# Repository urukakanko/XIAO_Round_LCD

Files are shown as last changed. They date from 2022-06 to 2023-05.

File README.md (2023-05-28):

# ラウンド液晶モジュール for XIAO RP2040（組立キット）

写真は作例です

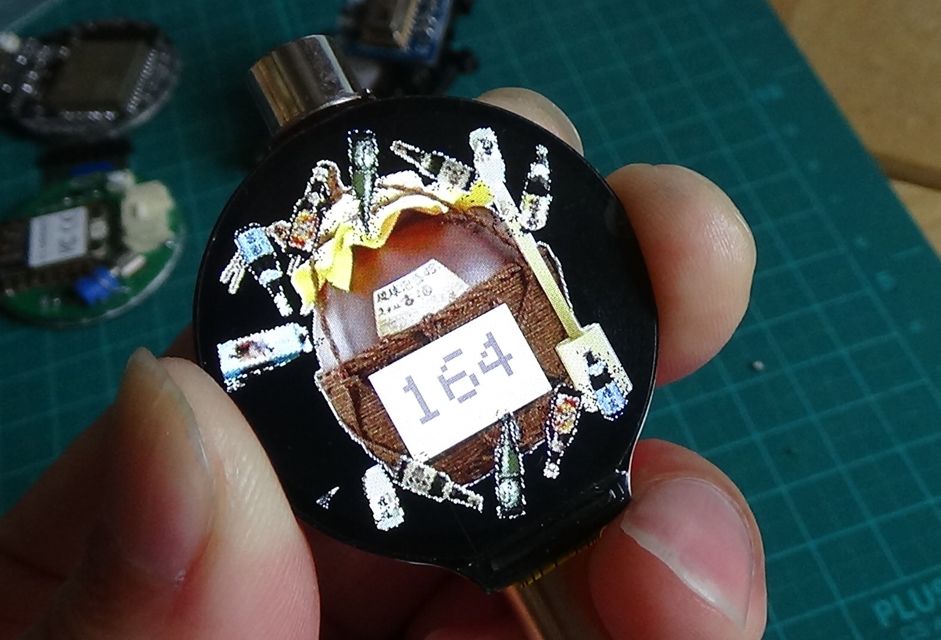
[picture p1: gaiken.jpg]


XIAO RP2040を使用して1.28インチ240ｘ240ドットの円形液晶を駆動する基板モジュールのキットです。

(XIAOシリーズでは、XIAO ESP32C3 や　nRF52840で液晶表示が出来る事を確認しています)

(なお、XIAO ESP32S3を実装する場合には懸念事項があります。以下ページで説明していますのでご参照下さい。)

https://github.com/urukakanko/XIAO_square_lcd

この製品はキットですので、ご自分で同梱の部品をハンダ付けしてください。

円形液晶の裏にXIAOを配置することで、とても小さくスリムな形状になりました。

円形液晶にはGC9A01というコントローラーが使用されていますが、対応したグラフィックライブラリが数種類公開されています。

本モジュールは「自分でSMT部品が実装できたり、グラフィックライブラリの使い方を理解して液晶モジュールを駆動出来る人」をターゲットにしております。

# 形状および回路図

以下に外形イメージを示します

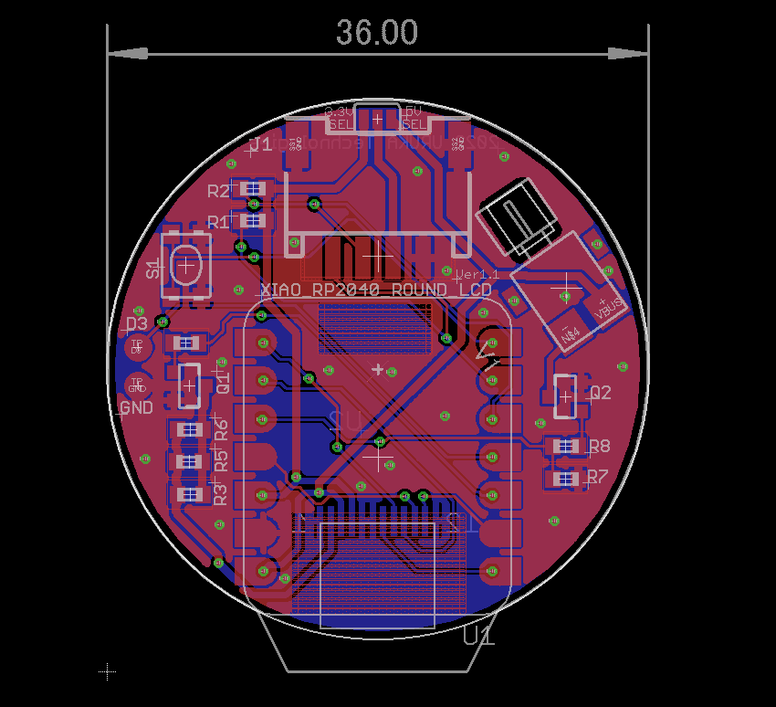
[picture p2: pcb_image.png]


以下に回路図を示します

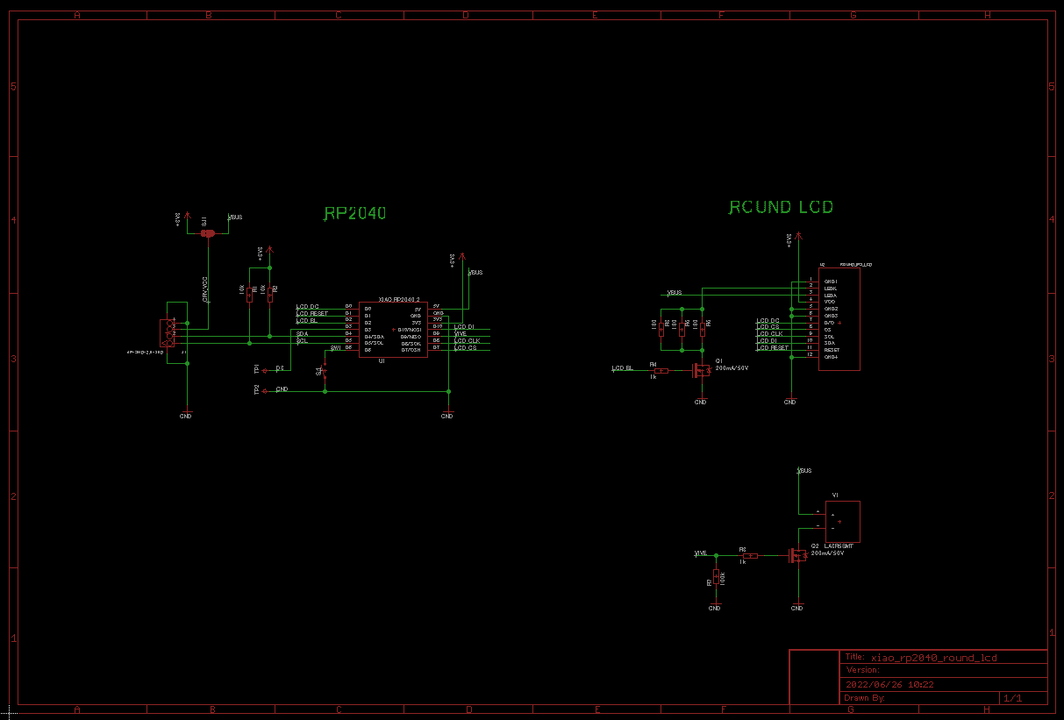
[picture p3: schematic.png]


# ピンアサイン

M5Stamp とLCDの制御信号とのピン接続は以下となります。

注意；IO番号はRP2040用です　ESP32C2では異なります

- SCLK:IO2/D8
- MOSI:IO3/D10
- DC:IO26/D0
- CS:IO1/D7
- RST:IO27/D1
- バックライト:IO28/D2　バックライトLEDのPIN設定は必ず行ってください。未設定だと端子がハイインピーダンスとなりバックライトが不安定になります。

基板上にタクトスイッチを１個実装しています

- SWポート：IO0/D6

また、I2C接続を想定したGROVEコネクタがあります

- 1PIN : SCL  IO7/D5　(I/F電圧レベルは3.3V)
- 2PIN : SDA  IO8/D4　(I/F電圧レベルは3.3V）
- 3PIN : VCC（5Vか3.3Vを選択可能）
- 4PIN : GND 

さらに小型FETを搭載すると、小型のバイブレーターなどアクチェータ１個を駆動する事が可能です

（こちらはについては扱い方次第で不具合も発生しますので、回路を読み解き自己責任で部品調達、実装してください）

- 制御ポート：IO4/D9

# 部品実装について

部品の実装（ハンダ付け方法）などについては、以下資料をご確認ください

https://github.com/urukakanko/XIAO_Round_LCD/blob/main/%E9%83%A8%E5%93%81%E5%AE%9F%E8%A3%85%E3%81%AE%E8%AA%AC%E6%98%8E.pdf

# 使用するツールやライブラリ

XIAO RP2040のArduinoやPythonの導入については以下をご確認ください

https://wiki.seeedstudio.com/XIAO-RP2040/

グラフィックライブラリについてはlovyan様のLovyanGFXにて動作確認をしています

https://github.com/lovyan03/LovyanGFX

他、GC9A01に対応したライブラリが使用可能と考えています。

なお、RP2040とGC9A01の組合せにてcircuit pythonでも動作する事を確認しています

# サンプルソース

LovyanGFXのスケッチの例より引用させて頂きました。

サンプルその１

https://github.com/urukakanko/XIAO_Round_LCD/tree/main/xiao2040_round_lcd_MeterSample

サンプルその２

https://github.com/urukakanko/XIAO_Round_LCD/tree/main/xiao2040_round_lcd_PartyParrot

サンプルその３

https://github.com/urukakanko/XIAO_Round_LCD/tree/main/xiao2040_round_clockSample

# そーたメイ様のつくるっちに対応して頂きました

ファームウェアは以下です

https://github.com/sohtamei/TuKuRutch.ext/blob/master/libraries/lovyanGFXpico/src/src.ino.uf2

ファームウェアを書込んでから、Cromeブラウザで以下にアクセスします　簡単なデモプログラムです「set config」ブロックにてROUNDXIAOを選択して下さい

https://sohta02.sakura.ne.jp/tukurutch/#000000531

# 表示例

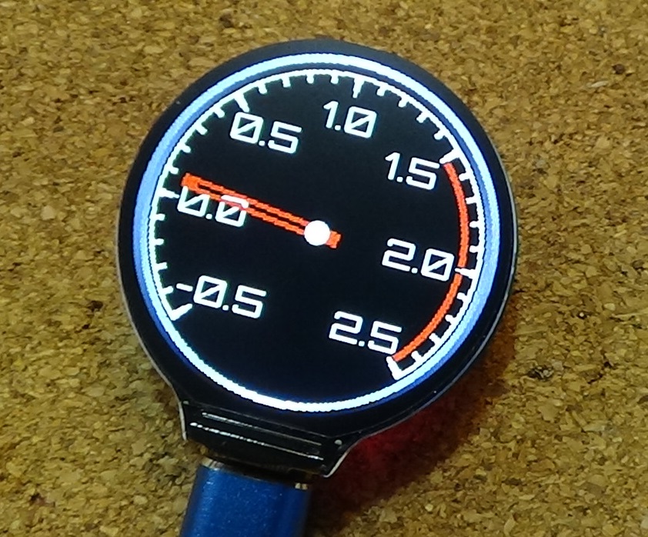
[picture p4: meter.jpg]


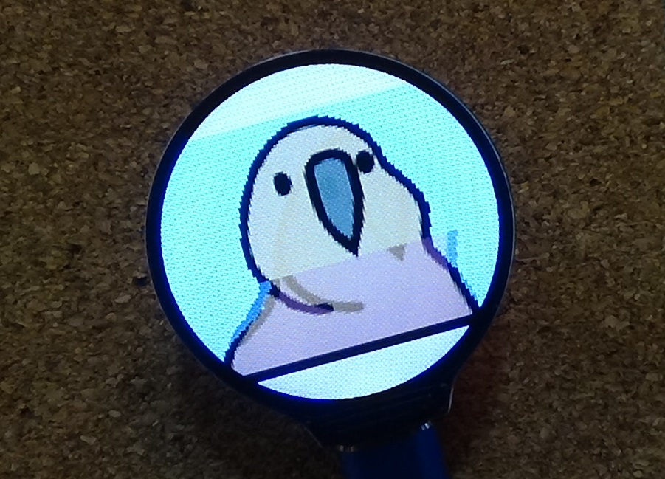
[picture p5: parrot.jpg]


# Shigezone様にて販売中です

https://www.shigezone.com/product/roundlcd1_28/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

# 製作者

ウルカテクノロジー
Hiroyuki Sunagawa

https://www.facebook.com/URUKA-Technologies-105478404379918

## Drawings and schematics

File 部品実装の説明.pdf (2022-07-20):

# 部品実装の説明

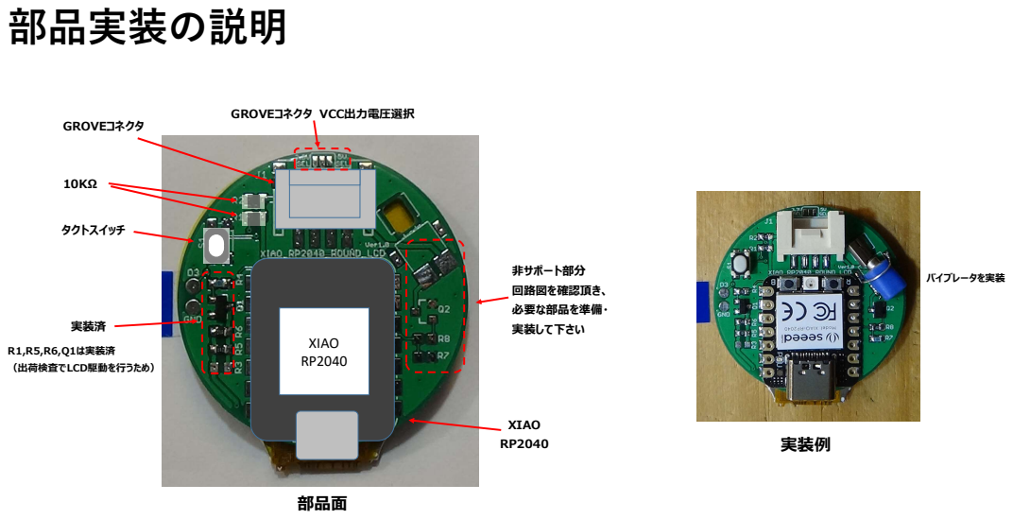
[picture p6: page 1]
タクトスイッチ; GROVEコネクタ; GROVEコネクタ VCC出力電圧選択; 非サポート部分 回路図を確認頂き、 必要な部品を準備・ 実装して下さい; 実装例; 部品面; バイブレータを実装 XIAO; XIAO RP2040; 実装済; R1,R5,R6,Q1は実装済 （出荷検査でLCD駆動を行うため）

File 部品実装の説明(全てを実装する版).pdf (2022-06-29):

# 部品実装の説明

### XIAO

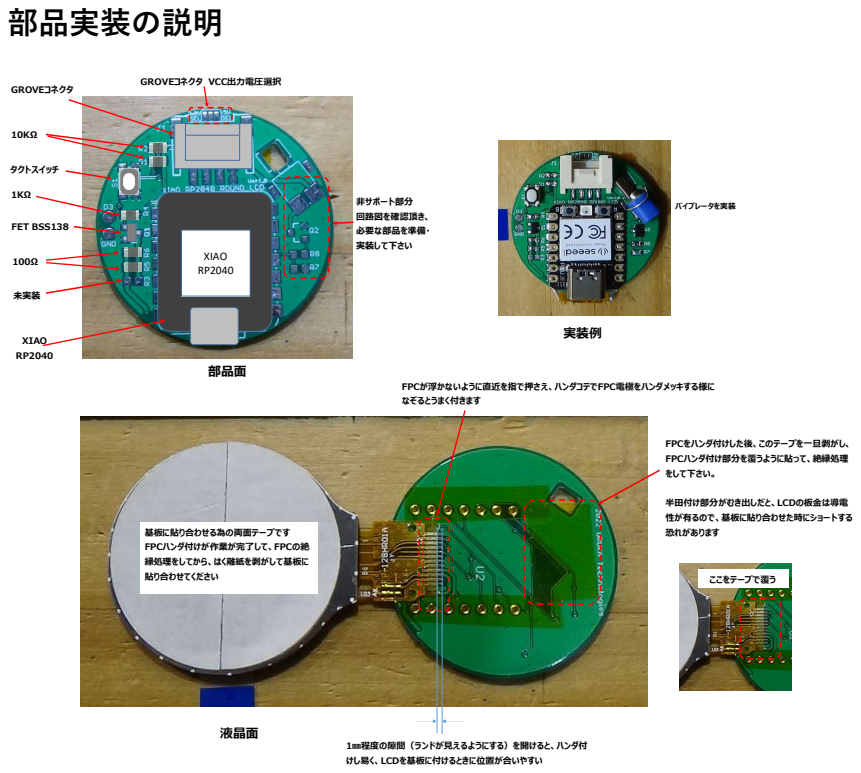
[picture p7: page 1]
タクトスイッチ; FET BSS138; 未実装; GROVEコネクタ; GROVEコネクタ VCC出力電圧選択; 非サポート部分 回路図を確認頂き、 必要な部品を準備・ 実装して下さい; 実装例; 部品面; バイブレータを実装; XIAO; 液晶面; FPCが浮かないように直近を指で押さえ、ハンダコテでFPC電極をハンダメッキする様に なぞるとうまく付きます; FPCをハンダ付けした後、このテープを一旦剥がし、 FPCハンダ付け部分を覆うように貼って、絶縁処理 をして下さい。; 半田付け部分がむき出しだと、LCDの板金は導電 性が有るので、基板に貼り合わせた時にショートする; 基板に貼り合わせる為の両面テープです; 恐れがあります; FPCハンダ付けが作業が完了して、FPCの絶 縁処理をしてから、はく離紙を剥がして基板に; 貼り合わせてください; ここをテープで覆う

1㎜程度の隙間（ランドが見えるようにする）を開けると、ハンダ付
けし易く、LCDを基板に付けるときに位置が合いやすい

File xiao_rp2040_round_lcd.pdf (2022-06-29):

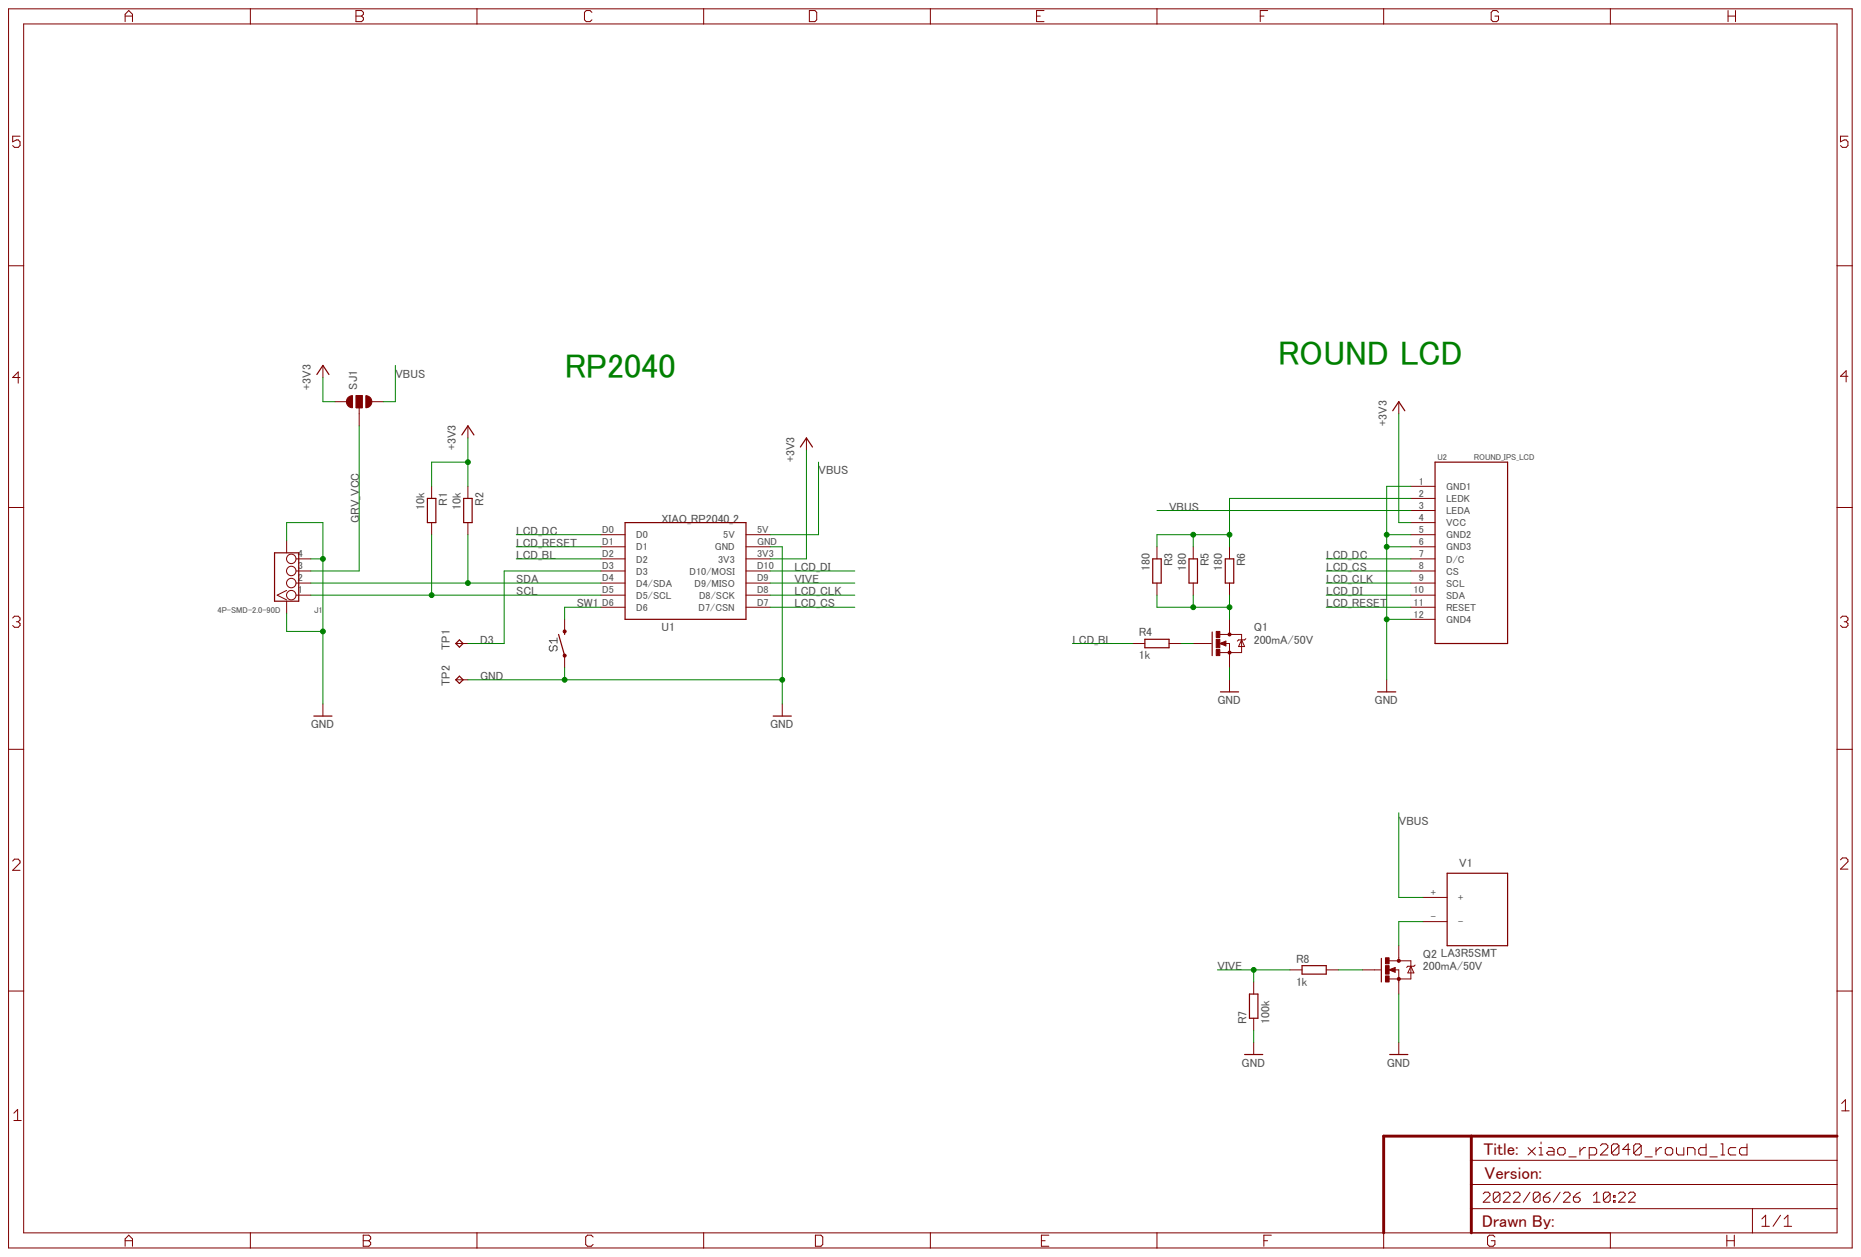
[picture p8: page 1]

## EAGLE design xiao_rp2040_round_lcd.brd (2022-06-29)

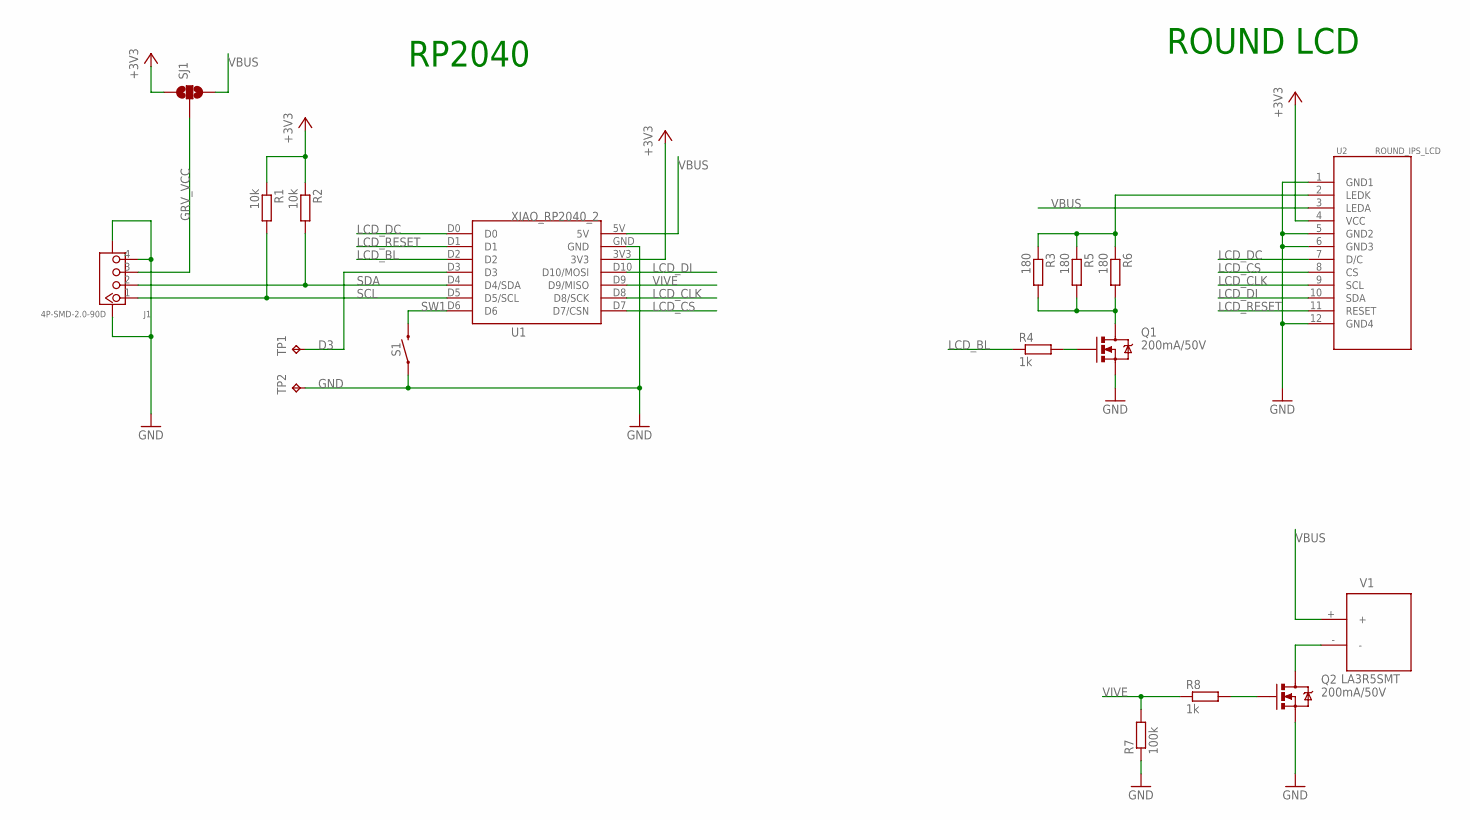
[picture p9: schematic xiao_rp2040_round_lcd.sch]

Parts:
J1: 4P-SMD-2.0-90D; HW4-SMD-2.0-90D
Q1, Q2: 200mA/50V; SOT23-3
R1, R2: 10k; R0603
R3, R5, R6: 180; R0603
R4, R8: 1k; R0603
R7: 100k; R0603
S1: TACT_SW_3X4; TACTILE_SWITCH_SMD_3X4MM
SJ1: SOLDERJUMPER_2WAYS; SJ_3
TP1, TP2: TPTP18R; TP18R
U1: XIAO_RP2040_2
U2: ROUND_IPS_LCD
V1: LA3R5SMT; LA3R5-2

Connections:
+3V3: R1.1, R2.1, SJ1.1, U1.3V3, U2.4 (VCC)
D3: TP1.TP, U1.D3
GND: J1.4, J1.SS1, J1.SS2, Q1.2 (S), Q2.2 (S), R7.1, S1.1, S1.2 (1), TP2.TP, U1.GND, U2.1 (GND1), U2.5 (GND2), U2.6 (GND3), U2.12 (GND4)
GRV_VCC: J1.3, SJ1.2
LCD_BL: R4.1, U1.D2
LCD_CLK: U1.D8 (D8/SCK), U2.9 (SCL)
LCD_CS: U1.D7 (D7/CSN), U2.8 (CS)
LCD_DC: U1.D0, U2.7 (D/C)
LCD_DI: U1.D10 (D10/MOSI), U2.10 (SDA)
LCD_RESET: U1.D1, U2.11 (RESET)
LED_K: R3.1, R5.1, R6.1, U2.2 (LEDK)
unnamed: Q1.1 (G), R4.2
unnamed: Q1.3 (D), R3.2, R5.2, R6.2
unnamed: Q2.3 (D), V1.-
unnamed: Q2.1 (G), R8.2
SCL: J1.1, R1.2, U1.D5 (D5/SCL)
SDA: J1.2, R2.2, U1.D4 (D4/SDA)
SW1: S1.3 (2), S1.4 (2), U1.D6
VBUS: SJ1.3, U1.5V, U2.3 (LEDA), V1.+
VIVE: R7.2, R8.1, U1.D9 (D9/MISO)

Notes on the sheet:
RP2040
ROUND LCD

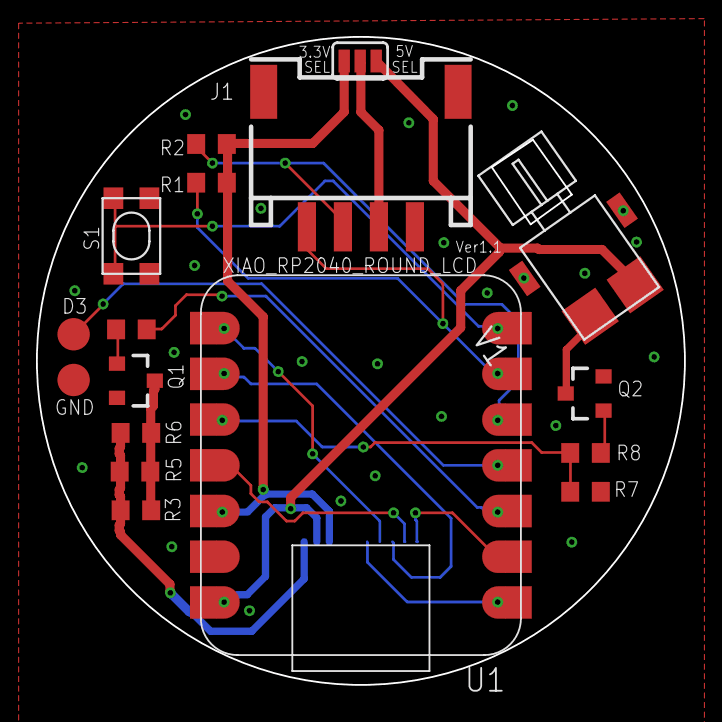
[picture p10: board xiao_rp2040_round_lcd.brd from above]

Board: 2 copper layers, 36.0 x 36.0 mm, 18 parts (1 on the bottom side), 20 nets.

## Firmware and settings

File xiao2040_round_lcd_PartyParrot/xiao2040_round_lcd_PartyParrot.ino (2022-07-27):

#define LGFX_USE_V1
#include <LovyanGFX.hpp>


class LGFX_RPICO_SPI_GC9A01 : public lgfx::LGFX_Device
{
    lgfx::Panel_GC9A01      _panel_instance;
    lgfx::Bus_SPI       _bus_instance;   // SPIバスのインスタンス
    //lgfx::Light_PWM     _light_instance;
  public:
    LGFX_RPICO_SPI_GC9A01(void)
    {
      { // バス制御の設定を行います。
        auto cfg = _bus_instance.config();    // バス設定用の構造体を取得します。

        // SPIバスの設定
        cfg.spi_host = 0 ;//SPI2_HOST;     // 使用するSPIを選択  ESP32-S2,C3 : SPI2_HOST or SPI3_HOST / ESP32 : VSPI_HOST or HSPI_HOST
        // ※ ESP-IDFバージョンアップに伴い、VSPI_HOST , HSPI_HOSTの記述は非推奨になるため、エラーが出る場合は代わりにSPI2_HOST , SPI3_HOSTを使用してください。
        cfg.spi_mode = 0;             // SPI通信モードを設定 (0 ~ 3)
        cfg.freq_write = 40000000;    // 送信時のSPIクロック (最大80MHz, 80MHzを整数で割った値に丸められます)
        cfg.freq_read  = 16000000;    // 受信時のSPIクロック
        //     cfg.spi_3wire  = true;        // 受信をMOSIピンで行う場合はtrueを設定
        //      cfg.use_lock   = true;        // トランザクションロックを使用する場合はtrueを設定
        //      cfg.dma_channel = SPI_DMA_CH_AUTO; // 使用するDMAチャンネルを設定 (0=DMA不使用 / 1=1ch / 2=ch / SPI_DMA_CH_AUTO=自動設定)
        // ※ ESP-IDFバージョンアップに伴い、DMAチャンネルはSPI_DMA_CH_AUTO(自動設定)が推奨になりました。1ch,2chの指定は非推奨になります。
        cfg.pin_sclk  = D8;  //IO2            // SPIのSCLKピン番号を設定
        cfg.pin_mosi  = D10; //IO3            // SPIのMOSIピン番号を設定
        cfg.pin_miso  = -1;            // SPIのMISOピン番号を設定 (-1 = disable)
        cfg.pin_dc    = D0;  //IO26           // SPIのD/Cピン番号を設定  (-1 = disable)
        // SDカードと共通のSPIバスを使う場合、MISOは省略せず必ず設定してください。
        _bus_instance.config(cfg);    // 設定値をバスに反映します。
        _panel_instance.setBus(&_bus_instance);      // バスをパネルにセットします。
      }

      { // 表示パネル制御の設定を行います。
        auto cfg = _panel_instance.config();    // 表示パネル設定用の構造体を取得します。
        cfg.pin_cs           =    D7;//IO1  // CSが接続されているピン番号   (-1 = disable)
        cfg.pin_rst          =    D1;//IO27  // RSTが接続されているピン番号  (-1 = disable)
        cfg.pin_busy         =    -1;  // BUSYが接続されているピン番号 (-1 = disable)
        // ※ 以下の設定値はパネル毎に一般的な初期値が設定されていますので、不明な項目はコメントアウトして試してみてください。
        cfg.memory_width     =   240;  // ドライバICがサポートしている最大の幅
        cfg.memory_height    =   240;  // ドライバICがサポートしている最大の高さ
        cfg.panel_width      =   240;  // 実際に表示可能な幅
        cfg.panel_height     =   240;  // 実際に表示可能な高さ
        cfg.offset_x         =     0;  // パネルのX方向オフセット量
        cfg.offset_y         =     0;  // パネルのY方向オフセット量
        cfg.offset_rotation  =     0;  // 回転方向の値のオフセット 0~7 (4~7は上下反転)
        cfg.dummy_read_pixel =     8;  // ピクセル読出し前のダミーリードのビット数
        cfg.dummy_read_bits  =     1;  // ピクセル以外のデータ読出し前のダミーリードのビット数
        cfg.readable         =  true;  // データ読出しが可能な場合 trueに設定
        cfg.invert           =  true;  // パネルの明暗が反転してしまう場合 trueに設定
        cfg.rgb_order        = false;  // パネルの赤と青が入れ替わってしまう場合 trueに設定
        cfg.dlen_16bit       = false;  // データ長を16bit単位で送信するパネルの場合 trueに設定
        cfg.bus_shared       =  true;  // SDカードとバスを共有している場合 trueに設定(drawJpgFile等でバス制御を行います)

        _panel_instance.config(cfg);
      }
      /*
        { // バックライト制御の設定を行います。（必要なければ削除）
          auto cfg = _light_instance.config();    // バックライト設定用の構造体を取得します。

          cfg.pin_bl = 7;              // バックライトが接続されているピン番号
          cfg.invert = false;           // バックライトの輝度を反転させる場合 true
          cfg.freq   = 44100;           // バックライトのPWM周波数
          cfg.pwm_channel = 3;          // 使用するPWMのチャンネル番号

          _light_instance.config(cfg);
          _panel_instance.setLight(&_light_instance);  // バックライトをパネルにセットします。
        }
      */
      setPanel(&_panel_instance); // 使用するパネルをセットします。
    }

};

LGFX_RPICO_SPI_GC9A01 lcd;

static LGFX_Sprite sprite[10];

static std::uint32_t count = 0;
static float zoom = 0;

extern const unsigned char parrot00[];
extern const unsigned char parrot01[];
extern const unsigned char parrot02[];
extern const unsigned char parrot03[];
extern const unsigned char parrot04[];
extern const unsigned char parrot05[];
extern const unsigned char parrot06[];
extern const unsigned char parrot07[];
extern const unsigned char parrot08[];
extern const unsigned char parrot09[];

#define bl D2 //IO28  バックライトピン設定
#define vib D9 //IO4   バイブレータピン設定

void setup()
{
  pinMode(bl, OUTPUT);
  digitalWrite(bl, HIGH);
  pinMode(vib, OUTPUT);
  digitalWrite(vib, LOW);
  
  lcd.init();
  lcd.setRotation(0);
  if (lcd.width() < lcd.height()) { lcd.setRotation(lcd.getRotation() ^ 1); }

  zoom = (float)lcd.width() / 128;
  float ztmp = (float)lcd.height() / 96;
  if (zoom > ztmp) { zoom = ztmp; }

  lcd.setPivot(lcd.width() >> 1, lcd.height() >> 1);
  lcd.fillScreen(0xFFFFFFU);

  sprite[0].createFromBmp(parrot00);
  sprite[1].createFromBmp(parrot01);
  sprite[2].createFromBmp(parrot02);
  sprite[3].createFromBmp(parrot03);
  sprite[4].createFromBmp(parrot04);
  sprite[5].createFromBmp(parrot05);
  sprite[6].createFromBmp(parrot06);
  sprite[7].createFromBmp(parrot07);
  sprite[8].createFromBmp(parrot08);
  sprite[9].createFromBmp(parrot09);
}

void loop() {
  if (++count == 10) count = 0;
  sprite[count].pushRotateZoom(&lcd, lcd.width() >> 1, lcd.height() >> 1, 0, zoom, zoom);
}

// The parrot image data is from this site.
// https://cultofthepartyparrot.com/

constexpr unsigned char parrot00[] = {
0x42, 0x4D, 0xEC, 0x0D, 0x00, 0x00, 0x00, 0x00, 0x00, 0x00, 0x32, 0x04, 0x00, 0x00, 0x28, 0x00, 
0x00, 0x00, 0x80, 0x00, 0x00, 0x00, 0x60, 0x00, 0x00, 0x00, 0x01, 0x00, 0x08, 0x00, 0x01, 0x00, 
0x00, 0x00, 0xBA, 0x09, 0x00, 0x00, 0x13, 0x0B, 0x00, 0x00, 0x13, 0x0B, 0x00, 0x00, 0xFF, 0x00, 
0x00, 0x00, 0xFF, 0x00, 0x00, 0x00, 0x00, 0x01, 0x00, 0x00, 0x00, 0x01, 0x08, 0x00, 0x08, 0x04, 
0x00, 0x00, 0x02, 0x06, 0x03, 0x00, 0x0B, 0x05, 0x08, 0x00, 0x06, 0x0A, 0x07, 0x00, 0x06, 0x08, 
0x0E, 0x00, 0x0E, 0x0B, 0x04, 0x00, 0x0F, 0x07, 0x12, 0x00, 0x0B, 0x0C, 0x12, 0x00, 0x16, 0x0B, 
0x12, 0x00, 0x0C, 0x0B, 0x17, 0x00, 0x0C, 0x10, 0x0D, 0x00, 0x13, 0x11, 0x08, 0x00, 0x12, 0x0C, 
0x1C, 0x00, 0x19, 0x0C, 0x1B, 0x00, 0x18, 0x10, 0x10, 0x00, 0x0A, 0x0D, 0x21, 0x00, 0x08, 0x13, 
0x10, 0x00, 0x1E, 0x0E, 0x1A, 0x00, 0x0A, 0x12, 0x18, 0x00, 0x1B, 0x15, 0x0E, 0x00, 0x1C, 0x10, 
0x1F, 0x00, 0x14, 0x11, 0x1F, 0x00, 0x12, 0x15, 0x13, 0x00, 0x23, 0x10, 0x24, 0x00, 0x1B, 0x10, 
0x28, 0x00, 0x0E, 0x15, 0x1C, 0x00, 0x0E, 0x1A, 0x0D, 0x00, 0x19, 0x19, 0x0D, 0x00, 0x11, 0x13, 
0x25, 0x00, 0x23, 0x13, 0x1F, 0x00, 0x12, 0x1A, 0x15, 0x00, 0x12, 0x13, 0x2E, 0x00, 0x25, 0x1A, 
0x16, 0x00, 0x2E, 0x14, 0x30, 0x00, 0x17, 0x18, 0x2C, 0x00, 0x20, 0x20, 0x0F, 0x00, 0x2D, 0x19, 
0x23, 0x00, 0x13, 0x1C, 0x23, 0x00, 0x13, 0x21, 0x13, 0x00, 0x17, 0x1F, 0x1A, 0x00, 0x24, 0x16, 
0x34, 0x00, 0x32, 0x14, 0x37, 0x00, 0x17, 0x17, 0x38, 0x00, 0x2E, 0x19, 0x2B, 0x00, 0x1C, 0x1D, 
0x32, 0x00, 0x15, 0x21, 0x29, 0x00, 0x32, 0x23, 0x1B, 0x00, 0x26, 0x26, 0x15, 0x00, 0x1D, 0x25, 
0x20, 0x00, 0x16, 0x29, 0x15, 0x00, 0x3B, 0x1A, 0x3B, 0x00, 0x1D, 0x1B, 0x43, 0x00, 0x2F, 0x1B, 
0x40, 0x00, 0x36, 0x1E, 0x34, 0x00, 0x3D, 0x20, 0x33, 0x00, 0x23, 0x21, 0x3D, 0x00, 0x3B, 0x20, 
0x3D, 0x00, 0x3A, 0x29, 0x22, 0x00, 0x44, 0x1D, 0x47, 0x00, 0x1F, 0x1F, 0x4D, 0x00, 0x2C, 0x2D, 
0x1A, 0x00, 0x1A, 0x28, 0x31, 0x00, 0x22, 0x2B, 0x27, 0x00, 0x37, 0x1F, 0x4D, 0x00, 0x3F, 0x23, 
0x41, 0x00, 0x26, 0x27, 0x48, 0x00, 0x47, 0x27, 0x3E, 0x00, 0x4E, 0x22, 0x4E, 0x00, 0x1F, 0x2F, 
0x39, 0x00, 0x25, 0x32, 0x2D, 0x00, 0x25, 0x26, 0x56, 0x00, 0x3F, 0x24, 0x59, 0x00, 0x1F, 0x39, 
0x1E, 0x00, 0x35, 0x37, 0x1E, 0x00, 0x47, 0x33, 0x27, 0x00, 0x53, 0x24, 0x58, 0x00, 0x4F, 0x2B, 
0x42, 0x00, 0x2B, 0x2C, 0x50, 0x00, 0x28, 0x28, 0x5F, 0x00, 0x4D, 0x2A, 0x4D, 0x00, 0x2A, 0x38, 
0x30, 0x00, 0x55, 0x30, 0x49, 0x00, 0x30, 0x2F, 0x59, 0x00, 0x60, 0x29, 0x62, 0x00, 0x2B, 0x2C, 
0x6B, 0x00, 0x49, 0x2B, 0x68, 0x00, 0x55, 0x2F, 0x59, 0x00, 0x26, 0x3A, 0x45, 0x00, 0x31, 0x3F, 
0x36, 0x00, 0x58, 0x3E, 0x2E, 0x00, 0x65, 0x2B, 0x6B, 0x00, 0x26, 0x46, 0x26, 0x00, 0x2F, 0x30, 
0x6F, 0x00, 0x5C, 0x32, 0x59, 0x00, 0x47, 0x46, 0x24, 0x00, 0x62, 0x36, 0x52, 0x00, 0x37, 0x36, 
0x61, 0x00, 0x51, 0x31, 0x75, 0x00, 0x32, 0x33, 0x7A, 0x00, 0x2A, 0x41, 0x4E, 0x00, 0x5E, 0x44, 
0x34, 0x00, 0x38, 0x47, 0x3D, 0x00, 0x65, 0x38, 0x66, 0x00, 0x75, 0x32, 0x79, 0x00, 0x2D, 0x52, 
0x2D, 0x00, 0x58, 0x35, 0x81, 0x00, 0x37, 0x37, 0x86, 0x00, 0x69, 0x4A, 0x37, 0x00, 0x3C, 0x3E, 
0x71, 0x00, 0x72, 0x3E, 0x61, 0x00, 0x53, 0x52, 0x2C, 0x00, 0x39, 0x4D, 0x46, 0x00, 0x30, 0x49, 
0x57, 0x00, 0x62, 0x37, 0x86, 0x00, 0x32, 0x58, 0x2B, 0x00, 0x72, 0x3D, 0x71, 0x00, 0x58, 0x56, 
0x30, 0x00, 0x2F, 0x5B, 0x31, 0x00, 0x3E, 0x3D, 0x93, 0x00, 0x86, 0x3A, 0x88, 0x00, 0x73, 0x52, 
0x3E, 0x00, 0x3F, 0x54, 0x4B, 0x00, 0x45, 0x45, 0x7E, 0x00, 0x69, 0x3D, 0x90, 0x00, 0x85, 0x48, 
0x6F, 0x00, 0x81, 0x45, 0x81, 0x00, 0x41, 0x43, 0xA1, 0x00, 0x37, 0x56, 0x66, 0x00, 0x7F, 0x5A, 
0x41, 0x00, 0x46, 0x5C, 0x4F, 0x00, 0x93, 0x3F, 0x98, 0x00, 0x38, 0x66, 0x36, 0x00, 0x63, 0x63, 
0x34, 0x00, 0x73, 0x43, 0xA0, 0x00, 0x4F, 0x4D, 0x8E, 0x00, 0x9C, 0x42, 0xA1, 0x00, 0x3D, 0x5D, 
0x6D, 0x00, 0x4C, 0x63, 0x55, 0x00, 0x95, 0x51, 0x7C, 0x00, 0x89, 0x62, 0x4A, 0x00, 0x9F, 0x45, 
0xA5, 0x00, 0x4B, 0x4B, 0xB3, 0x00, 0x50, 0x53, 0x97, 0x00, 0x51, 0x68, 0x5A, 0x00, 0x7E, 0x4A, 
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
};

constexpr unsigned char parrot01[] = {
0x42, 0x4D, 0xFE, 0x0D, 0x00, 0x00, 0x00, 0x00, 0x00, 0x00, 0x32, 0x04, 0x00, 0x00, 0x28, 0x00, 
0x00, 0x00, 0x80, 0x00, 0x00, 0x00, 0x60, 0x00, 0x00, 0x00, 0x01, 0x00, 0x08, 0x00, 0x01, 0x00, 
0x00, 0x00, 0xCC, 0x09, 0x00, 0x00, 0x13, 0x0B, 0x00, 0x00, 0x13, 0x0B, 0x00, 0x00, 0xFF, 0x00, 
0x00, 0x00, 0xFF, 0x00, 0x00, 0x00, 0x00, 0x01, 0x00, 0x00, 0x00, 0x01, 0x08, 0x00, 0x08, 0x04, 
0x00, 0x00, 0x02, 0x06, 0x03, 0x00, 0x0B, 0x05, 0x08, 0x00, 0x06, 0x0A, 0x07, 0x00, 0x06, 0x08, 
0x0E, 0x00, 0x0E, 0x0B, 0x04, 0x00, 0x0F, 0x07, 0x12, 0x00, 0x0B, 0x0C, 0x12, 0x00, 0x16, 0x0B, 
0x12, 0x00, 0x0C, 0x0B, 0x17, 0x00, 0x0C, 0x10, 0x0D, 0x00, 0x13, 0x11, 0x08, 0x00, 0x12, 0x0C, 
0x1C, 0x00, 0x19, 0x0C, 0x1B, 0x00, 0x18, 0x10, 0x10, 0x00, 0x0A, 0x0D, 0x21, 0x00, 0x08, 0x13, 
0x10, 0x00, 0x1E, 0x0E, 0x1A, 0x00, 0x0A, 0x12, 0x18, 0x00, 0x1B, 0x15, 0x0E, 0x00, 0x1C, 0x10, 
0x1F, 0x00, 0x14, 0x11, 0x1F, 0x00, 0x12, 0x15, 0x13, 0x00, 0x23, 0x10, 0x24, 0x00, 0x1B, 0x10, 
0x28, 0x00, 0x0E, 0x15, 0x1C, 0x00, 0x0E, 0x1A, 0x0D, 0x00, 0x19, 0x19, 0x0D, 0x00, 0x11, 0x13, 
0x25, 0x00, 0x23, 0x13, 0x1F, 0x00, 0x12, 0x1A, 0x15, 0x00, 0x12, 0x13, 0x2E, 0x00, 0x25, 0x1A, 
0x16, 0x00, 0x2E, 0x14, 0x30, 0x00, 0x17, 0x18, 0x2C, 0x00, 0x20, 0x20, 0x0F, 0x00, 0x2D, 0x19, 
0x23, 0x00, 0x13, 0x1C, 0x23, 0x00, 0x13, 0x21, 0x13, 0x00, 0x17, 0x1F, 0x1A, 0x00, 0x24, 0x16, 
0x34, 0x00, 0x32, 0x14, 0x37, 0x00, 0x17, 0x17, 0x38, 0x00, 0x2E, 0x19, 0x2B, 0x00, 0x1C, 0x1D, 
0x32, 0x00, 0x15, 0x21, 0x29, 0x00, 0x32, 0x23, 0x1B, 0x00, 0x26, 0x26, 0x15, 0x00, 0x1D, 0x25, 
0x20, 0x00, 0x16, 0x29, 0x15, 0x00, 0x3B, 0x1A, 0x3B, 0x00, 0x1D, 0x1B, 0x43, 0x00, 0x2F, 0x1B, 
0x40, 0x00, 0x36, 0x1E, 0x34, 0x00, 0x3D, 0x20, 0x33, 0x00, 0x23, 0x21, 0x3D, 0x00, 0x3B, 0x20, 
0x3D, 0x00, 0x3A, 0x29, 0x22, 0x00, 0x44, 0x1D, 0x47, 0x00, 0x1F, 0x1F, 0x4D, 0x00, 0x2C, 0x2D, 
0x1A, 0x00, 0x1A, 0x28, 0x31, 0x00, 0x22, 0x2B, 0x27, 0x00, 0x37, 0x1F, 0x4D, 0x00, 0x3F, 0x23, 
0x41, 0x00, 0x26, 0x27, 0x48, 0x00, 0x47, 0x27, 0x3E, 0x00, 0x4E, 0x22, 0x4E, 0x00, 0x1F, 0x2F, 
0x39, 0x00, 0x25, 0x32, 0x2D, 0x00, 0x25, 0x26, 0x56, 0x00, 0x3F, 0x24, 0x59, 0x00, 0x1F, 0x39, 
0x1E, 0x00, 0x35, 0x37, 0x1E, 0x00, 0x47, 0x33, 0x27, 0x00, 0x53, 0x24, 0x58, 0x00, 0x4F, 0x2B, 
0x42, 0x00, 0x2B, 0x2C, 0x50, 0x00, 0x28, 0x28, 0x5F, 0x00, 0x4D, 0x2A, 0x4D, 0x00, 0x2A, 0x38, 
0x30, 0x00, 0x55, 0x30, 0x49, 0x00, 0x30, 0x2F, 0x59, 0x00, 0x60, 0x29, 0x62, 0x00, 0x2B, 0x2C, 
0x6B, 0x00, 0x49, 0x2B, 0x68, 0x00, 0x55, 0x2F, 0x59, 0x00, 0x26, 0x3A, 0x45, 0x00, 0x31, 0x3F, 
0x36, 0x00, 0x58, 0x3E, 0x2E, 0x00, 0x65, 0x2B, 0x6B, 0x00, 0x26, 0x46, 0x26, 0x00, 0x2F, 0x30, 
0x6F, 0x00, 0x5C, 0x32, 0x59, 0x00, 0x47, 0x46, 0x24, 0x00, 0x62, 0x36, 0x52, 0x00, 0x37, 0x36, 
0x61, 0x00, 0x51, 0x31, 0x75, 0x00, 0x32, 0x33, 0x7A, 0x00, 0x2A, 0x41, 0x4E, 0x00, 0x5E, 0x44, 
0x34, 0x00, 0x38, 0x47, 0x3D, 0x00, 0x65, 0x38, 0x66, 0x00, 0x75, 0x32, 0x79, 0x00, 0x2D, 0x52, 
0x2D, 0x00, 0x58, 0x35, 0x81, 0x00, 0x37, 0x37, 0x86, 0x00, 0x69, 0x4A, 0x37, 0x00, 0x3C, 0x3E, 
0x71, 0x00, 0x72, 0x3E, 0x61, 0x00, 0x53, 0x52, 0x2C, 0x00, 0x39, 0x4D, 0x46, 0x00, 0x30, 0x49, 
0x57, 0x00, 0x62, 0x37, 0x86, 0x00, 0x32, 0x58, 0x2B, 0x00, 0x72, 0x3D, 0x71, 0x00, 0x58, 0x56, 
0x30, 0x00, 0x2F, 0x5B, 0x31, 0x00, 0x3E, 0x3D, 0x93, 0x00, 0x86, 0x3A, 0x88, 0x00, 0x73, 0x52, 
0x3E, 0x00, 0x3F, 0x54, 0x4B, 0x00, 0x45, 0x45, 0x7E, 0x00, 0x69, 0x3D, 0x90, 0x00, 0x85, 0x48, 
0x6F, 0x00, 0x81, 0x45, 0x81, 0x00, 0x41, 0x43, 0xA1, 0x00, 0x37, 0x56, 0x66, 0x00, 0x7F, 0x5A, 
0x41, 0x00, 0x46, 0x5C, 0x4F, 0x00, 0x93, 0x3F, 0x98, 0x00, 0x38, 0x66, 0x36, 0x00, 0x63, 0x63, 
0x34, 0x00, 0x73, 0x43, 0xA0, 0x00, 0x4F, 0x4D, 0x8E, 0x00, 0x9C, 0x42, 0xA1, 0x00, 0x3D, 0x5D, 
0x6D, 0x00, 0x4C, 0x63, 0x55, 0x00, 0x95, 0x51, 0x7C, 0x00, 0x89, 0x62, 0x4A, 0x00, 0x9F, 0x45, 
0xA5, 0x00, 0x4B, 0x4B, 0xB3, 0x00, 0x50, 0x53, 0x97, 0x00, 0x51, 0x68, 0x5A, 0x00, 0x7E, 0x4A, 
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
};

constexpr unsigned char parrot02[] = {
0x42, 0x4D, 0x22, 0x0E, 0x00, 0x00, 0x00, 0x00, 0x00, 0x00, 0x32, 0x04, 0x00, 0x00, 0x28, 0x00, 
0x00, 0x00, 0x80, 0x00, 0x00, 0x00, 0x60, 0x00, 0x00, 0x00, 0x01, 0x00, 0x08, 0x00, 0x01, 0x00, 
0x00, 0x00, 0xF0, 0x09, 0x00, 0x00, 0x13, 0x0B, 0x00, 0x00, 0x13, 0x0B, 0x00, 0x00, 0xFF, 0x00, 
0x00, 0x00, 0xFF, 0x00, 0x00, 0x00, 0x00, 0x01, 0x00, 0x00, 0x00, 0x01, 0x08, 0x00, 0x08, 0x04, 
0x00, 0x00, 0x02, 0x06, 0x03, 0x00, 0x0B, 0x05, 0x08, 0x00, 0x06, 0x0A, 0x07, 0x00, 0x06, 0x08, 
0x0E, 0x00, 0x0E, 0x0B, 0x04, 0x00, 0x0F, 0x07, 0x12, 0x00, 0x0B, 0x0C, 0x12, 0x00, 0x16, 0x0B, 
0x12, 0x00, 0x0C, 0x0B, 0x17, 0x00, 0x0C, 0x10, 0x0D, 0x00, 0x13, 0x11, 0x08, 0x00, 0x12, 0x0C, 
0x1C, 0x00, 0x19, 0x0C, 0x1B, 0x00, 0x18, 0x10, 0x10, 0x00, 0x0A, 0x0D, 0x21, 0x00, 0x08, 0x13, 
0x10, 0x00, 0x1E, 0x0E, 0x1A, 0x00, 0x0A, 0x12, 0x18, 0x00, 0x1B, 0x15, 0x0E, 0x00, 0x1C, 0x10, 
0x1F, 0x00, 0x14, 0x11, 0x1F, 0x00, 0x12, 0x15, 0x13, 0x00, 0x23, 0x10, 0x24, 0x00, 0x1B, 0x10, 
0x28, 0x00, 0x0E, 0x15, 0x1C, 0x00, 0x0E, 0x1A, 0x0D, 0x00, 0x19, 0x19, 0x0D, 0x00, 0x11, 0x13, 
0x25, 0x00, 0x23, 0x13, 0x1F, 0x00, 0x12, 0x1A, 0x15, 0x00, 0x12, 0x13, 0x2E, 0x00, 0x25, 0x1A, 
0x16, 0x00, 0x2E, 0x14, 0x30, 0x00, 0x17, 0x18, 0x2C, 0x00, 0x20, 0x20, 0x0F, 0x00, 0x2D, 0x19, 
0x23, 0x00, 0x13, 0x1C, 0x23, 0x00, 0x13, 0x21, 0x13, 0x00, 0x17, 0x1F, 0x1A, 0x00, 0x24, 0x16, 
0x34, 0x00, 0x32, 0x14, 0x37, 0x00, 0x17, 0x17, 0x38, 0x00, 0x2E, 0x19, 0x2B, 0x00, 0x1C, 0x1D, 
0x32, 0x00, 0x15, 0x21, 0x29, 0x00, 0x32, 0x23, 0x1B, 0x00, 0x26, 0x26, 0x15, 0x00, 0x1D, 0x25, 
0x20, 0x00, 0x16, 0x29, 0x15, 0x00, 0x3B, 0x1A, 0x3B, 0x00, 0x1D, 0x1B, 0x43, 0x00, 0x2F, 0x1B, 
0x40, 0x00, 0x36, 0x1E, 0x34, 0x00, 0x3D, 0x20, 0x33, 0x00, 0x23, 0x21, 0x3D, 0x00, 0x3B, 0x20, 
0x3D, 0x00, 0x3A, 0x29, 0x22, 0x00, 0x44, 0x1D, 0x47, 0x00, 0x1F, 0x1F, 0x4D, 0x00, 0x2C, 0x2D, 
0x1A, 0x00, 0x1A, 0x28, 0x31, 0x00, 0x22, 0x2B, 0x27, 0x00, 0x37, 0x1F, 0x4D, 0x00, 0x3F, 0x23, 
0x41, 0x00, 0x26, 0x27, 0x48, 0x00, 0x47, 0x27, 0x3E, 0x00, 0x4E, 0x22, 0x4E, 0x00, 0x1F, 0x2F, 
0x39, 0x00, 0x25, 0x32, 0x2D, 0x00, 0x25, 0x26, 0x56, 0x00, 0x3F, 0x24, 0x59, 0x00, 0x1F, 0x39, 
0x1E, 0x00, 0x35, 0x37, 0x1E, 0x00, 0x47, 0x33, 0x27, 0x00, 0x53, 0x24, 0x58, 0x00, 0x4F, 0x2B, 
0x42, 0x00, 0x2B, 0x2C, 0x50, 0x00, 0x28, 0x28, 0x5F, 0x00, 0x4D, 0x2A, 0x4D, 0x00, 0x2A, 0x38, 
0x30, 0x00, 0x55, 0x30, 0x49, 0x00, 0x30, 0x2F, 0x59, 0x00, 0x60, 0x29, 0x62, 0x00, 0x2B, 0x2C, 
0x6B, 0x00, 0x49, 0x2B, 0x68, 0x00, 0x55, 0x2F, 0x59, 0x00, 0x26, 0x3A, 0x45, 0x00, 0x31, 0x3F, 
0x36, 0x00, 0x58, 0x3E, 0x2E, 0x00, 0x65, 0x2B, 0x6B, 0x00, 0x26, 0x46, 0x26, 0x00, 0x2F, 0x30, 
0x6F, 0x00, 0x5C, 0x32, 0x59, 0x00, 0x47, 0x46, 0x24, 0x00, 0x62, 0x36, 0x52, 0x00, 0x37, 0x36, 
0x61, 0x00, 0x51, 0x31, 0x75, 0x00, 0x32, 0x33, 0x7A, 0x00, 0x2A, 0x41, 0x4E, 0x00, 0x5E, 0x44, 
0x34, 0x00, 0x38, 0x47, 0x3D, 0x00, 0x65, 0x38, 0x66, 0x00, 0x75, 0x32, 0x79, 0x00, 0x2D, 0x52, 
0x2D, 0x00, 0x58, 0x35, 0x81, 0x00, 0x37, 0x37, 0x86, 0x00, 0x69, 0x4A, 0x37, 0x00, 0x3C, 0x3E, 
0x71, 0x00, 0x72, 0x3E, 0x61, 0x00, 0x53, 0x52, 0x2C, 0x00, 0x39, 0x4D, 0x46, 0x00, 0x30, 0x49, 
0x57, 0x00, 0x62, 0x37, 0x86, 0x00, 0x32, 0x58, 0x2B, 0x00, 0x72, 0x3D, 0x71, 0x00, 0x58, 0x56, 
0x30, 0x00, 0x2F, 0x5B, 0x31, 0x00, 0x3E, 0x3D, 0x93, 0x00, 0x86, 0x3A, 0x88, 0x00, 0x73, 0x52, 
0x3E, 0x00, 0x3F, 0x54, 0x4B, 0x00, 0x45, 0x45, 0x7E, 0x00, 0x69, 0x3D, 0x90, 0x00, 0x85, 0x48, 
0x6F, 0x00, 0x81, 0x45, 0x81, 0x00, 0x41, 0x43, 0xA1, 0x00, 0x37, 0x56, 0x66, 0x00, 0x7F, 0x5A, 
0x41, 0x00, 0x46, 0x5C, 0x4F, 0x00, 0x93, 0x3F, 0x98, 0x00, 0x38, 0x66, 0x36, 0x00, 0x63, 0x63, 
0x34, 0x00, 0x73, 0x43, 0xA0, 0x00, 0x4F, 0x4D, 0x8E, 0x00, 0x9C, 0x42, 0xA1, 0x00, 0x3D, 0x5D, 
0x6D, 0x00, 0x4C, 0x63, 0x55, 0x00, 0x95, 0x51, 0x7C, 0x00, 0x89, 0x62, 0x4A, 0x00, 0x9F, 0x45, 
0xA5, 0x00, 0x4B, 0x4B, 0xB3, 0x00, 0x50, 0x53, 0x97, 0x00, 0x51, 0x68, 0x5A, 0x00, 0x7E, 0x4A, 
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
};

constexpr unsigned char parrot03[] = {
0x42, 0x4D, 0xFA, 0x0D, 0x00, 0x00, 0x00, 0x00, 0x00, 0x00, 0x32, 0x04, 0x00, 0x00, 0x28, 0x00, 
0x00, 0x00, 0x80, 0x00, 0x00, 0x00, 0x60, 0x00, 0x00, 0x00, 0x01, 0x00, 0x08, 0x00, 0x01, 0x00, 
0x00, 0x00, 0xC8, 0x09, 0x00, 0x00, 0x13, 0x0B, 0x00, 0x00, 0x13, 0x0B, 0x00, 0x00, 0xFF, 0x00, 
0x00, 0x00, 0xFF, 0x00, 0x00, 0x00, 0x00, 0x01, 0x00, 0x00, 0x00, 0x01, 0x08, 0x00, 0x08, 0x04, 
0x00, 0x00, 0x02, 0x06, 0x03, 0x00, 0x0B, 0x05, 0x08, 0x00, 0x06, 0x0A, 0x07, 0x00, 0x06, 0x08, 
0x0E, 0x00, 0x0E, 0x0B, 0x04, 0x00, 0x0F, 0x07, 0x12, 0x00, 0x0B, 0x0C, 0x12, 0x00, 0x16, 0x0B, 
0x12, 0x00, 0x0C, 0x0B, 0x17, 0x00, 0x0C, 0x10, 0x0D, 0x00, 0x13, 0x11, 0x08, 0x00, 0x12, 0x0C, 
0x1C, 0x00, 0x19, 0x0C, 0x1B, 0x00, 0x18, 0x10, 0x10, 0x00, 0x0A, 0x0D, 0x21, 0x00, 0x08, 0x13, 
0x10, 0x00, 0x1E, 0x0E, 0x1A, 0x00, 0x0A, 0x12, 0x18, 0x00, 0x1B, 0x15, 0x0E, 0x00, 0x1C, 0x10, 
0x1F, 0x00, 0x14, 0x11, 0x1F, 0x00, 0x12, 0x15, 0x13, 0x00, 0x23, 0x10, 0x24, 0x00, 0x1B, 0x10, 
0x28, 0x00, 0x0E, 0x15, 0x1C, 0x00, 0x0E, 0x1A, 0x0D, 0x00, 0x19, 0x19, 0x0D, 0x00, 0x11, 0x13, 
0x25, 0x00, 0x23, 0x13, 0x1F, 0x00, 0x12, 0x1A, 0x15, 0x00, 0x12, 0x13, 0x2E, 0x00, 0x25, 0x1A, 
0x16, 0x00, 0x2E, 0x14, 0x30, 0x00, 0x17, 0x18, 0x2C, 0x00, 0x20, 0x20, 0x0F, 0x00, 0x2D, 0x19, 
0x23, 0x00, 0x13, 0x1C, 0x23, 0x00, 0x13, 0x21, 0x13, 0x00, 0x17, 0x1F, 0x1A, 0x00, 0x24, 0x16, 
0x34, 0x00, 0x32, 0x14, 0x37, 0x00, 0x17, 0x17, 0x38, 0x00, 0x2E, 0x19, 0x2B, 0x00, 0x1C, 0x1D, 
0x32, 0x00, 0x15, 0x21, 0x29, 0x00, 0x32, 0x23, 0x1B, 0x00, 0x26, 0x26, 0x15, 0x00, 0x1D, 0x25, 
0x20, 0x00, 0x16, 0x29, 0x15, 0x00, 0x3B, 0x1A, 0x3B, 0x00, 0x1D, 0x1B, 0x43, 0x00, 0x2F, 0x1B, 
0x40, 0x00, 0x36, 0x1E, 0x34, 0x00, 0x3D, 0x20, 0x33, 0x00, 0x23, 0x21, 0x3D, 0x00, 0x3B, 0x20, 
0x3D, 0x00, 0x3A, 0x29, 0x22, 0x00, 0x44, 0x1D, 0x47, 0x00, 0x1F, 0x1F, 0x4D, 0x00, 0x2C, 0x2D, 
0x1A, 0x00, 0x1A, 0x28, 0x31, 0x00, 0x22, 0x2B, 0x27, 0x00, 0x37, 0x1F, 0x4D, 0x00, 0x3F, 0x23, 
0x41, 0x00, 0x26, 0x27, 0x48, 0x00, 0x47, 0x27, 0x3E, 0x00, 0x4E, 0x22, 0x4E, 0x00, 0x1F, 0x2F, 
0x39, 0x00, 0x25, 0x32, 0x2D, 0x00, 0x25, 0x26, 0x56, 0x00, 0x3F, 0x24, 0x59, 0x00, 0x1F, 0x39, 
0x1E, 0x00, 0x35, 0x37, 0x1E, 0x00, 0x47, 0x33, 0x27, 0x00, 0x53, 0x24, 0x58, 0x00, 0x4F, 0x2B, 
0x42, 0x00, 0x2B, 0x2C, 0x50, 0x00, 0x28, 0x28, 0x5F, 0x00, 0x4D, 0x2A, 0x4D, 0x00, 0x2A, 0x38, 
0x30, 0x00, 0x55, 0x30, 0x49, 0x00, 0x30, 0x2F, 0x59, 0x00, 0x60, 0x29, 0x62, 0x00, 0x2B, 0x2C, 
0x6B, 0x00, 0x49, 0x2B, 0x68, 0x00, 0x55, 0x2F, 0x59, 0x00, 0x26, 0x3A, 0x45, 0x00, 0x31, 0x3F, 
0x36, 0x00, 0x58, 0x3E, 0x2E, 0x00, 0x65, 0x2B, 0x6B, 0x00, 0x26, 0x46, 0x26, 0x00, 0x2F, 0x30, 
0x6F, 0x00, 0x5C, 0x32, 0x59, 0x00, 0x47, 0x46, 0x24, 0x00, 0x62, 0x36, 0x52, 0x00, 0x37, 0x36, 
0x61, 0x00, 0x51, 0x31, 0x75, 0x00, 0x32, 0x33, 0x7A, 0x00, 0x2A, 0x41, 0x4E, 0x00, 0x5E, 0x44, 
0x34, 0x00, 0x38, 0x47, 0x3D, 0x00, 0x65, 0x38, 0x66, 0x00, 0x75, 0x32, 0x79, 0x00, 0x2D, 0x52, 
0x2D, 0x00, 0x58, 0x35, 0x81, 0x00, 0x37, 0x37, 0x86, 0x00, 0x69, 0x4A, 0x37, 0x00, 0x3C, 0x3E, 
0x71, 0x00, 0x72, 0x3E, 0x61, 0x00, 0x53, 0x52, 0x2C, 0x00, 0x39, 0x4D, 0x46, 0x00, 0x30, 0x49, 
0x57, 0x00, 0x62, 0x37, 0x86, 0x00, 0x32, 0x58, 0x2B, 0x00, 0x72, 0x3D, 0x71, 0x00, 0x58, 0x56, 
0x30, 0x00, 0x2F, 0x5B, 0x31, 0x00, 0x3E, 0x3D, 0x93, 0x00, 0x86, 0x3A, 0x88, 0x00, 0x73, 0x52, 
0x3E, 0x00, 0x3F, 0x54, 0x4B, 0x00, 0x45, 0x45, 0x7E, 0x00, 0x69, 0x3D, 0x90, 0x00, 0x85, 0x48, 
0x6F, 0x00, 0x81, 0x45, 0x81, 0x00, 0x41, 0x43, 0xA1, 0x00, 0x37, 0x56, 0x66, 0x00, 0x7F, 0x5A, 
0x41, 0x00, 0x46, 0x5C, 0x4F, 0x00, 0x93, 0x3F, 0x98, 0x00, 0x38, 0x66, 0x36, 0x00, 0x63, 0x63, 
0x34, 0x00, 0x73, 0x43, 0xA0, 0x00, 0x4F, 0x4D, 0x8E, 0x00, 0x9C, 0x42, 0xA1, 0x00, 0x3D, 0x5D, 
0x6D, 0x00, 0x4C, 0x63, 0x55, 0x00, 0x95, 0x51, 0x7C, 0x00, 0x89, 0x62, 0x4A, 0x00, 0x9F, 0x45, 
0xA5, 0x00, 0x4B, 0x4B, 0xB3, 0x00, 0x50, 0x53, 0x97, 0x00, 0x51, 0x68, 0x5A, 0x00, 0x7E, 0x4A, 
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
};
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

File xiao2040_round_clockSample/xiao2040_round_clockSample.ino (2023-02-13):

#define LGFX_USE_V1
#include <LovyanGFX.hpp>

class LGFX_RPICO_SPI_GC9A01 : public lgfx::LGFX_Device
{
    lgfx::Panel_GC9A01      _panel_instance;
    lgfx::Bus_SPI       _bus_instance;   // SPIバスのインスタンス
    //lgfx::Light_PWM     _light_instance;
  public:
    LGFX_RPICO_SPI_GC9A01(void)
    {
      { // バス制御の設定を行います。
        auto cfg = _bus_instance.config();    // バス設定用の構造体を取得します。

        // SPIバスの設定
        cfg.spi_host = 0 ;//SPI2_HOST;     // 使用するSPIを選択  ESP32-S2,C3 : SPI2_HOST or SPI3_HOST / ESP32 : VSPI_HOST or HSPI_HOST
        // ※ ESP-IDFバージョンアップに伴い、VSPI_HOST , HSPI_HOSTの記述は非推奨になるため、エラーが出る場合は代わりにSPI2_HOST , SPI3_HOSTを使用してください。
        cfg.spi_mode = 0;             // SPI通信モードを設定 (0 ~ 3)
        cfg.freq_write = 40000000;    // 送信時のSPIクロック (最大80MHz, 80MHzを整数で割った値に丸められます)
        cfg.freq_read  = 16000000;    // 受信時のSPIクロック
        //     cfg.spi_3wire  = true;        // 受信をMOSIピンで行う場合はtrueを設定
        //      cfg.use_lock   = true;        // トランザクションロックを使用する場合はtrueを設定
        //      cfg.dma_channel = SPI_DMA_CH_AUTO; // 使用するDMAチャンネルを設定 (0=DMA不使用 / 1=1ch / 2=ch / SPI_DMA_CH_AUTO=自動設定)
        // ※ ESP-IDFバージョンアップに伴い、DMAチャンネルはSPI_DMA_CH_AUTO(自動設定)が推奨になりました。1ch,2chの指定は非推奨になります。
        cfg.pin_sclk = 2;            // SPIのSCLKピン番号を設定
        cfg.pin_mosi = 3;            // SPIのMOSIピン番号を設定
        cfg.pin_miso = 4;            // SPIのMISOピン番号を設定 (-1 = disable)
        cfg.pin_dc   = 26 ;           // SPIのD/Cピン番号を設定  (-1 = disable)
        // SDカードと共通のSPIバスを使う場合、MISOは省略せず必ず設定してください。
        _bus_instance.config(cfg);    // 設定値をバスに反映します。
        _panel_instance.setBus(&_bus_instance);      // バスをパネルにセットします。
      }

      { // 表示パネル制御の設定を行います。
        auto cfg = _panel_instance.config();    // 表示パネル設定用の構造体を取得します。
        cfg.pin_cs           =    1;  // CSが接続されているピン番号   (-1 = disable)
        cfg.pin_rst          =    27;  // RSTが接続されているピン番号  (-1 = disable)
        cfg.pin_busy         =    -1;  // BUSYが接続されているピン番号 (-1 = disable)
        // ※ 以下の設定値はパネル毎に一般的な初期値が設定されていますので、不明な項目はコメントアウトして試してみてください。
        cfg.memory_width     =   240;  // ドライバICがサポートしている最大の幅
        cfg.memory_height    =   240;  // ドライバICがサポートしている最大の高さ
        cfg.panel_width      =   240;  // 実際に表示可能な幅
        cfg.panel_height     =   240;  // 実際に表示可能な高さ
        cfg.offset_x         =     0;  // パネルのX方向オフセット量
        cfg.offset_y         =     0;  // パネルのY方向オフセット量
        cfg.offset_rotation  =     0;  // 回転方向の値のオフセット 0~7 (4~7は上下反転)
        cfg.dummy_read_pixel =     8;  // ピクセル読出し前のダミーリードのビット数
        cfg.dummy_read_bits  =     1;  // ピクセル以外のデータ読出し前のダミーリードのビット数
        cfg.readable         =  true;  // データ読出しが可能な場合 trueに設定
        cfg.invert           =  true;  // パネルの明暗が反転してしまう場合 trueに設定
        cfg.rgb_order        = false;  // パネルの赤と青が入れ替わってしまう場合 trueに設定
        cfg.dlen_16bit       = false;  // データ長を16bit単位で送信するパネルの場合 trueに設定
        cfg.bus_shared       =  true;  // SDカードとバスを共有している場合 trueに設定(drawJpgFile等でバス制御を行います)

        _panel_instance.config(cfg);
      }
      /*
        { // バックライト制御の設定を行います。（必要なければ削除）
          auto cfg = _light_instance.config();    // バックライト設定用の構造体を取得します。

          cfg.pin_bl = 7;              // バックライトが接続されているピン番号
          cfg.invert = false;           // バックライトの輝度を反転させる場合 true
          cfg.freq   = 44100;           // バックライトのPWM周波数
          cfg.pwm_channel = 3;          // 使用するPWMのチャンネル番号

          _light_instance.config(cfg);
          _panel_instance.setLight(&_light_instance);  // バックライトをパネルにセットします。
        }
      */
      setPanel(&_panel_instance); // 使用するパネルをセットします。
    }

};

LGFX_RPICO_SPI_GC9A01 lcd;

static LGFX_Sprite canvas(&lcd);       // オフスクリーン描画用バッファ
static LGFX_Sprite clockbase(&canvas); // 時計の文字盤パーツ
static LGFX_Sprite needle1(&canvas);   // 長針・短針パーツ
static LGFX_Sprite shadow1(&canvas);   // 長針・短針の影パーツ
static LGFX_Sprite needle2(&canvas);   // 秒針パーツ
static LGFX_Sprite shadow2(&canvas);   // 秒針の影パーツ

static constexpr uint64_t oneday = 86400000; // 1日 = 1000msec x 60sec x 60min x 24hour = 86400000
static uint64_t count = rand() % oneday;    // 現在時刻 (ミリ秒カウンタ)
static int32_t width = 239;             // 時計の縦横画像サイズ
static int32_t halfwidth = width >> 1;  // 時計盤の中心座標
static auto transpalette = 0;           // 透過色パレット番号
static float zoom;                      // 表示倍率

#ifdef min
#undef min
#endif

void setup(void)
{

  pinMode(28, OUTPUT);
  digitalWrite(28, HIGH);
  pinMode(4, OUTPUT);
  digitalWrite(4, LOW); 
  lcd.init();

  zoom = (float)(std::min(lcd.width(), lcd.height())) / width; // 表示が画面にフィットするよう倍率を調整

  lcd.setPivot(lcd.width() >> 1, lcd.height() >> 1); // 時計描画時の中心を画面中心に合わせる

  canvas.setColorDepth(lgfx::palette_4bit);  // 各部品を４ビットパレットモードで準備する
  clockbase.setColorDepth(lgfx::palette_4bit);
  needle1.setColorDepth(lgfx::palette_4bit);
  shadow1.setColorDepth(lgfx::palette_4bit);
  needle2.setColorDepth(lgfx::palette_4bit);
  shadow2.setColorDepth(lgfx::palette_4bit);
// パレットの初期色はグレースケールのグラデーションとなっており、
// 0番が黒(0,0,0)、15番が白(255,255,255)
// 1番～14番は黒から白へ段階的に明るさが変化している
//
// パレットを使う場合、描画関数は色の代わりに0～15のパレット番号を指定する

  canvas.createSprite(width, width); // メモリ確保
  clockbase.createSprite(width, width);
  needle1.createSprite(9, 119);
  shadow1.createSprite(9, 119);
  needle2.createSprite(3, 119);
  shadow2.createSprite(3, 119);

  canvas.fillScreen(transpalette); // 透過色で背景を塗り潰す (create直後は0埋めされているので省略可能)
  clockbase.fillScreen(transpalette);
  needle1.fillScreen(transpalette);
  shadow1.fillScreen(transpalette);

  clockbase.setTextFont(4);           // フォント種類を変更(時計盤の文字用)
  clockbase.setTextDatum(lgfx::middle_center);
  clockbase.fillCircle(halfwidth, halfwidth, halfwidth    ,  6); // 時計盤の背景の円を塗る
  clockbase.drawCircle(halfwidth, halfwidth, halfwidth - 1, 15);
  for (int i = 1; i <= 60; ++i) {
    float rad = i * 6 * - 0.0174532925;              // 時計盤外周の目盛り座標を求める
    float cosy = - cos(rad) * (halfwidth * 10 / 11);
    float sinx = - sin(rad) * (halfwidth * 10 / 11);
    bool flg = 0 == (i % 5);      // ５目盛り毎フラグ
    clockbase.fillCircle(halfwidth + sinx + 1, halfwidth + cosy + 1, flg * 3 + 1,  4); // 目盛りを描画
    clockbase.fillCircle(halfwidth + sinx    , halfwidth + cosy    , flg * 3 + 1, 12);
    if (flg) {                    // 文字描画
      cosy = - cos(rad) * (halfwidth * 10 / 13);
      sinx = - sin(rad) * (halfwidth * 10 / 13);
      clockbase.setTextColor(1);
      clockbase.drawNumber(i/5, halfwidth + sinx + 1, halfwidth + cosy + 4);
      clockbase.setTextColor(15);
      clockbase.drawNumber(i/5, halfwidth + sinx    , halfwidth + cosy + 3);
    }
  }
  clockbase.setTextFont(7);

  needle1.setPivot(4, 100);  // 針パーツの回転中心座標を設定する
  shadow1.setPivot(4, 100);
  needle2.setPivot(1, 100);
  shadow2.setPivot(1, 100);
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

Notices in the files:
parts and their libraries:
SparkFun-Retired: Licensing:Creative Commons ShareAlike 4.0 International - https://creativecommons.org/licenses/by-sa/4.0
